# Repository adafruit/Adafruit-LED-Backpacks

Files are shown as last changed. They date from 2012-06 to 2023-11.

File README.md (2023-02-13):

# Adafruit LED Matrix backpacks PCBs

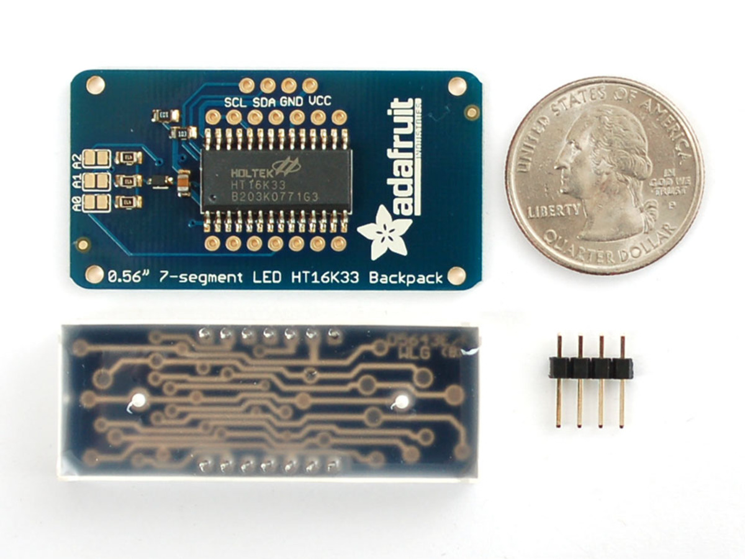
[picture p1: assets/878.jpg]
&nbsp; 
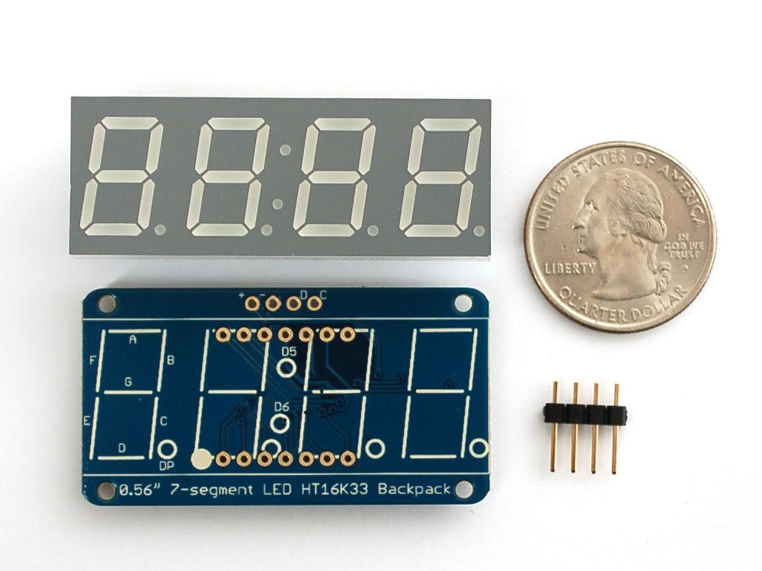
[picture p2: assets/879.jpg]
&nbsp; 
&nbsp; 
<br />
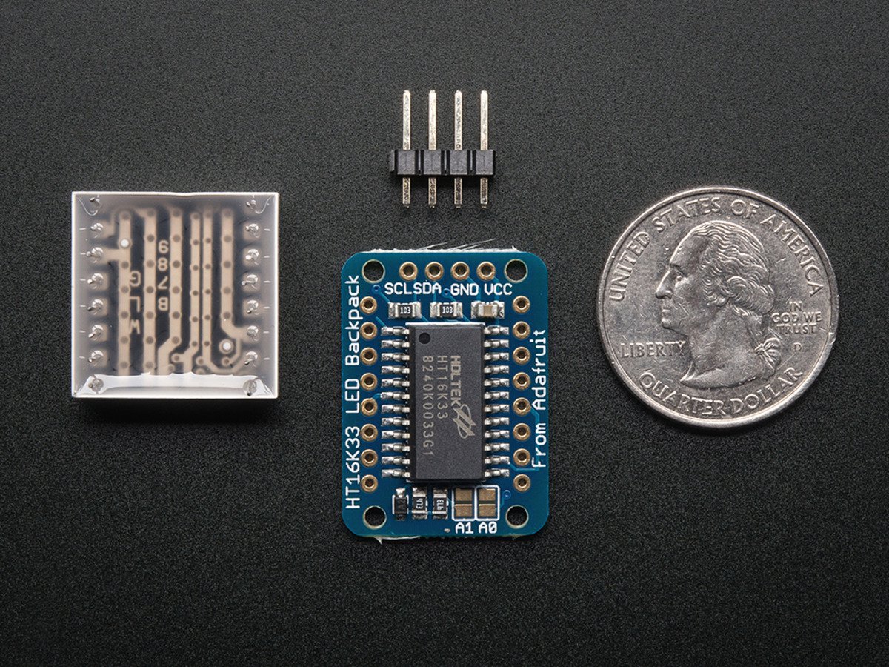
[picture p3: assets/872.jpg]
&nbsp; 
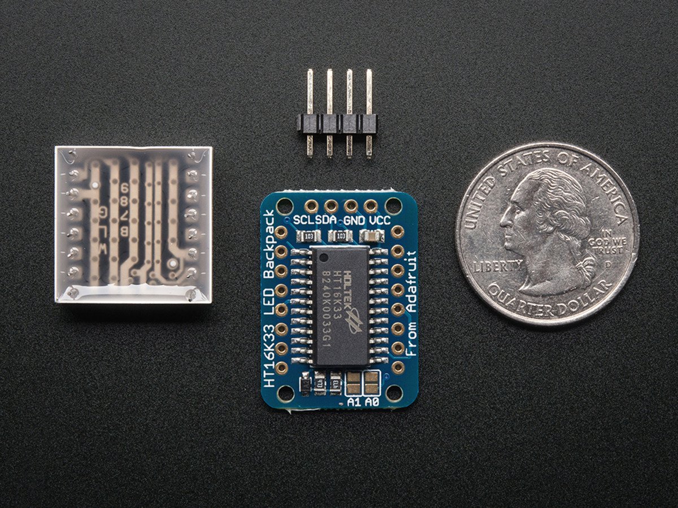
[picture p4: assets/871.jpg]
&nbsp; 
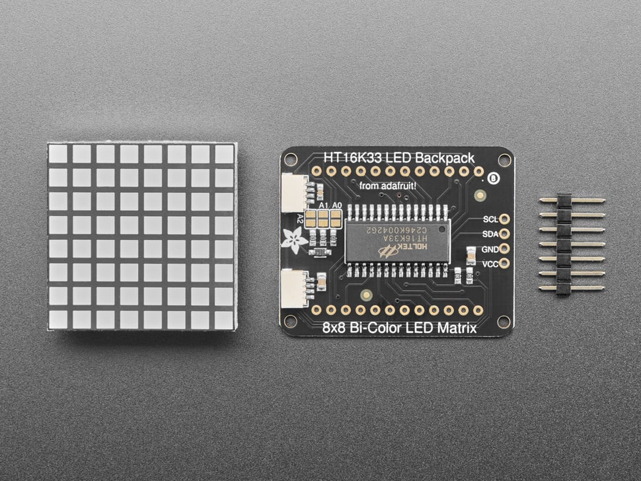
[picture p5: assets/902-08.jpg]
&nbsp; 
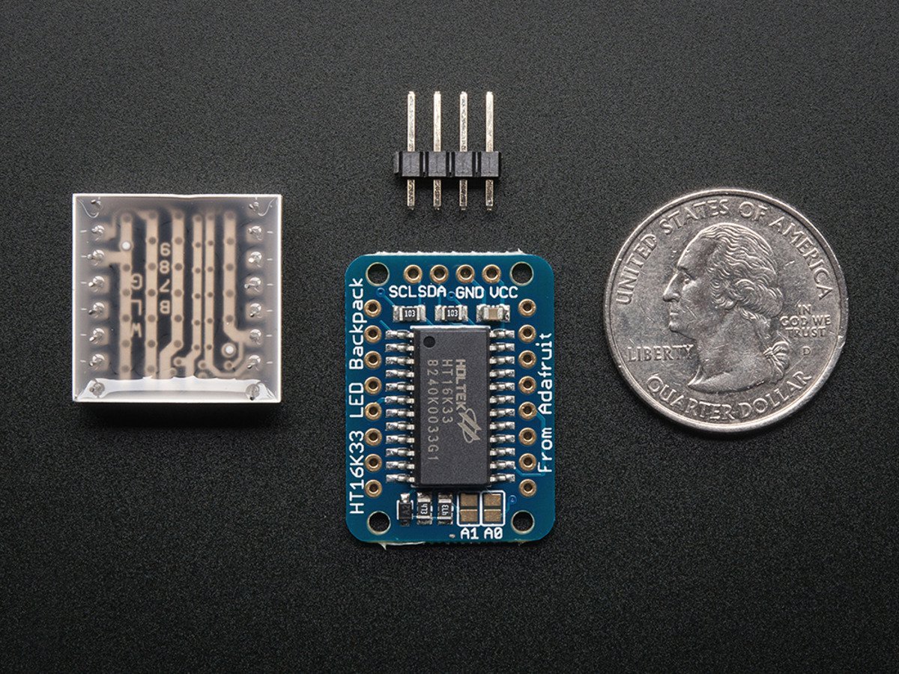
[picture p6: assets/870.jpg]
<br />

What's better than a single LED? Lots of LEDs! A fun way to make a small display is to use an 8x8 matrix or a 4-digit 7-segment display. Matrices like these are 'multiplexed' - so to control all the seven-segment LEDs you need 14 pins. That's a lot of pins, and there are driver chips like the MAX7219 that can control a matrix for you but there's a lot of wiring to set up and they take up a ton of space. Here at Adafruit we feel your pain! After all, wouldn't it be awesome if you could control a matrix without tons of wiring? That's where these adorable LED matrix backpacks come in. We have them in two flavors - a mini 8x8 and a 4-digit 0.56" 7-segment. 

These are the Eagle CAD files for the Adafruit LED Backpack breakouts:
- http://www.adafruit.com/products/878
- http://www.adafruit.com/products/879
- http://www.adafruit.com/products/880
- http://www.adafruit.com/products/881
- http://www.adafruit.com/products/872
- http://www.adafruit.com/products/871
- http://www.adafruit.com/products/870
- https://www.adafruit.com/product/902

These displays use I2C to communicate, 2 pins are required to 
interface. There are multiple selectable I2C addresses. For backpacks 
with 2 Address Select pins: 0x70, 0x71, 0x72 or 0x73. For backpacks 
with 3 Address Select pins: 0x70 thru 0x77

### License

Adafruit invests time and resources providing this open source design, please support Adafruit and open-source hardware by purchasing products from [Adafruit](https://www.adafruit.com)!

All text above must be included in any redistribution

Designed by Limor Fried/Ladyada for Adafruit Industries.
Creative Commons Attribution/Share-Alike, all text above must be included in any redistribution. 
See license.txt for additional information.

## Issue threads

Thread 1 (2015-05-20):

http://www.adafruit.com/products/1427 missing

boelle, 2015-05-20:
i was going to use this one for a project and would like to just drop it in eagle as a part... the pitch between picth i know, but between the rows is to much guess work... any chance this could be added to product info or the board added to git?

Closed 2019-03-19.

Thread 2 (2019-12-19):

Pin numbering on 1.2" 7-segment clock display?

adamwolf, 2019-12-19:
Hi folks!

@matthewbeckler and I were having trouble interpreting the schematic and PCB, because they didn't seem to match around the first two pins of the display.  I opened up the source files in my editor, rather than the exported images, and I noticed that the pins for the display are not in numerical order.

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

I'm curious what the reasoning is for this.  If this was a mistake, is there some way I can help fix it or would that involve internal libraries or something?

Anyway, thanks for all the good work!

Docteh, 2021-07-03:
I ran into this just today looking at the various board layouts.

The PCB file is consistent with the shipped product, so the top pin does connect to Pin 4 of the HT16K33, and the second pin (labeled pin 1 on the PCB) goes to Pin 2 on the HT16K33.

Another interesting quirk is that the PCB layout appears to show the rectangle bleeding off of the board, but on the actual product the silk screen lines are on the board.

ShearonA, 2021-11-21:
This took me way longer to find than it should have.  As the previous two people have identified, the board is correct, but the schematic is incorrect. The schematic shows the decimals/colons being connected to COM0, and they are connected to COM2, with digit 1 (of 4) being connected to COM0, digit 2 (of 4) being connected to COM1, digit 3 being connected to COM3, and digit 4 being connected to COM5.

It doesn't matter if one is using the Arduino libraries, but if you are building your own library in C, this will take a while to figure out that your code won't work if you program to the schematic.

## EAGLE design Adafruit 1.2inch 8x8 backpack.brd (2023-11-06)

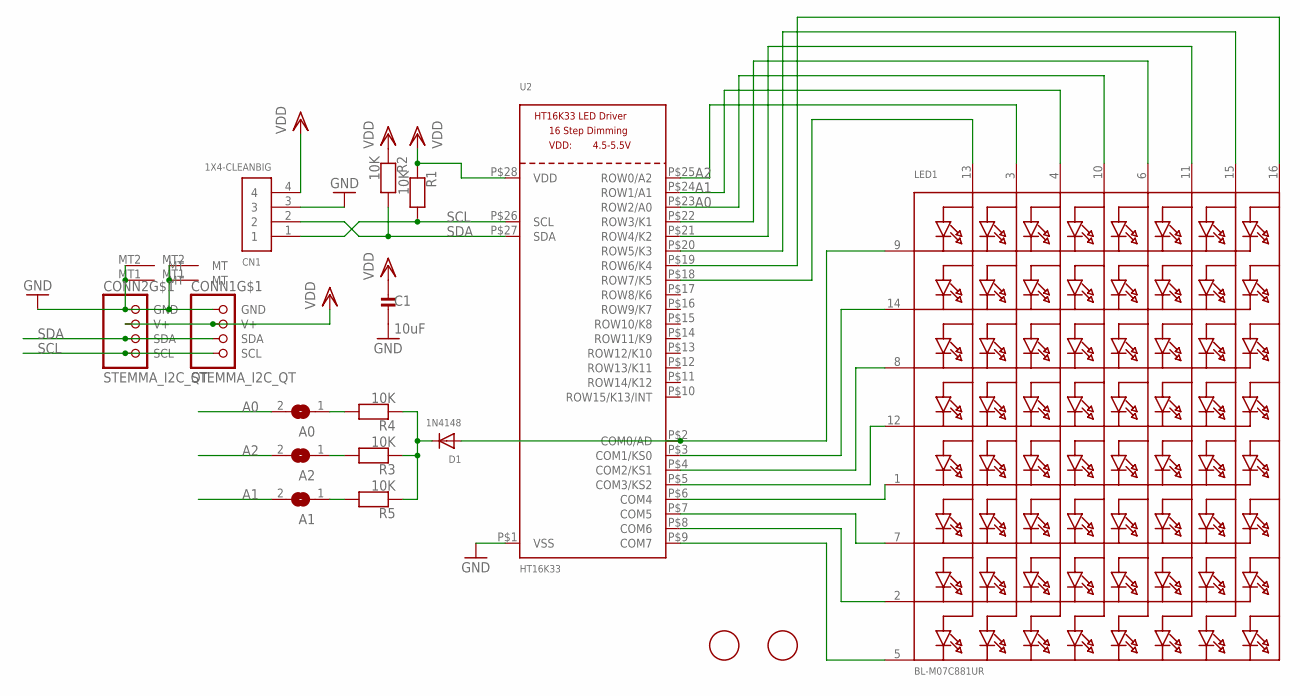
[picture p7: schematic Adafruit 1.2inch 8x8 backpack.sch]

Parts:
A0, A1, A2: SOLDERJUMPERREFLOW_NOPASTE; SOLDERJUMPER_REFLOW_NOPASTE
C1: 10uF; 0805-NO
CN1: 1X4-CLEANBIG; 1X04-CLEANBIG
CONN1, CONN2: STEMMA_I2C_QT; JST_SH4
D1: 1N4148; SOD-323
LED1: BL-M07C881UR; SEGMENT_BL-M12A881UR
R1, R2, R3, R4, R5: 10K; 0603-NO
U2: HT16K33; SOP28_300MIL
U$1, U$2: FIDUCIAL; FIDUCIAL_1MM

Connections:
A0: A0.2, LED1.10 (A4), U2.P$23 (ROW2/A0)
A1: A1.2, LED1.4 (A3), U2.P$24 (ROW1/A1)
A2: A2.2, LED1.3 (A2), U2.P$25 (ROW0/A2)
GND: C1.2, CN1.3, CONN1.1 (GND), CONN1.MT1 (MT), CONN1.MT2 (MT), CONN2.1 (GND), CONN2.MT1 (MT), CONN2.MT2 (MT), U2.P$1 (VSS)
unnamed: LED1.5 (K8), U2.P$9 (COM7)
unnamed: LED1.2 (K7), U2.P$8 (COM6)
unnamed: LED1.7 (K6), U2.P$7 (COM5)
unnamed: LED1.1 (K5), U2.P$6 (COM4)
unnamed: LED1.12 (K4), U2.P$5 (COM3/KS2)
unnamed: LED1.8 (K3), U2.P$4 (COM2/KS1)
unnamed: LED1.14 (K2), U2.P$3 (COM1/KS0)
unnamed: D1.A, LED1.9 (K1), U2.P$2 (COM0/AD)
unnamed: A1.1, R5.2
unnamed: LED1.6 (A5), U2.P$22 (ROW3/K1)
unnamed: LED1.11 (A6), U2.P$21 (ROW4/K2)
unnamed: D1.C, R3.1, R4.1, R5.1
unnamed: LED1.13 (A1), U2.P$18 (ROW7/K5)
unnamed: A2.1, R3.2
unnamed: A0.1, R4.2
SCL: CN1.1, CONN1.4 (SCL), CONN2.4 (SCL), R1.2, U2.P$26 (SCL)
SDA: CN1.2, CONN1.3 (SDA), CONN2.3 (SDA), R2.2, U2.P$27 (SDA)
SEG_F: LED1.15 (A7), U2.P$20 (ROW5/K3)
SEG_G: LED1.16 (A8), U2.P$19 (ROW6/K4)
VDD: C1.1, CN1.4, CONN1.2 (V+), CONN2.2 (V+), R1.1, R2.1, U2.P$28 (VDD)

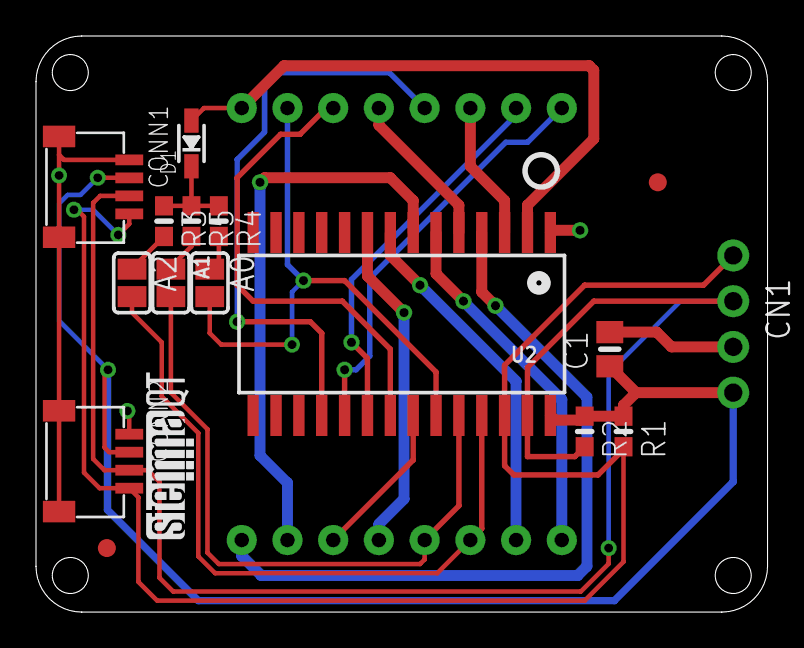
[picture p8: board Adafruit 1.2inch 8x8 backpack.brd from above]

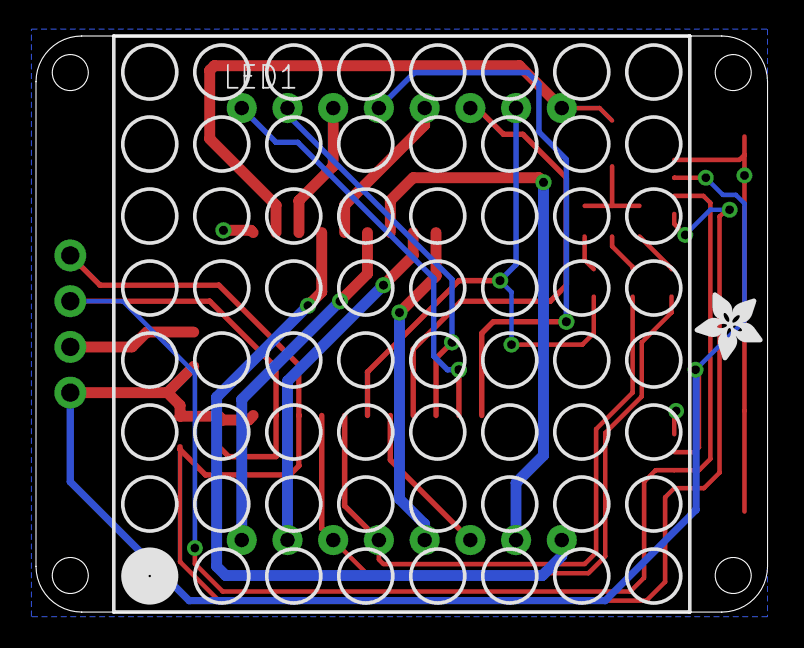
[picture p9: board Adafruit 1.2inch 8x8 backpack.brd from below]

Board: 2 copper layers, 40.6 x 32.0 mm, 34 parts (6 on the bottom side), 24 nets.

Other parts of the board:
PLABEL0: PLABEL0
PLABEL1: PLABEL1
PLABEL2: PLABEL2
PLABEL3: PLABEL3
PLABEL4: PLABEL4
PLABEL5: PLABEL5
PLABEL6: PLABEL6
PLABEL7: PLABEL7
PLABEL8: PLABEL8
PLABEL9: PLABEL9
PLABEL10: PLABEL10
PLABEL11: PLABEL11
PLABEL12: PLABEL12
PLABEL13: PLABEL13
U$3: ADAFRUIT_3.5MM
U$4: PCBFEAT-REV-040
U$5: STEMMAQT

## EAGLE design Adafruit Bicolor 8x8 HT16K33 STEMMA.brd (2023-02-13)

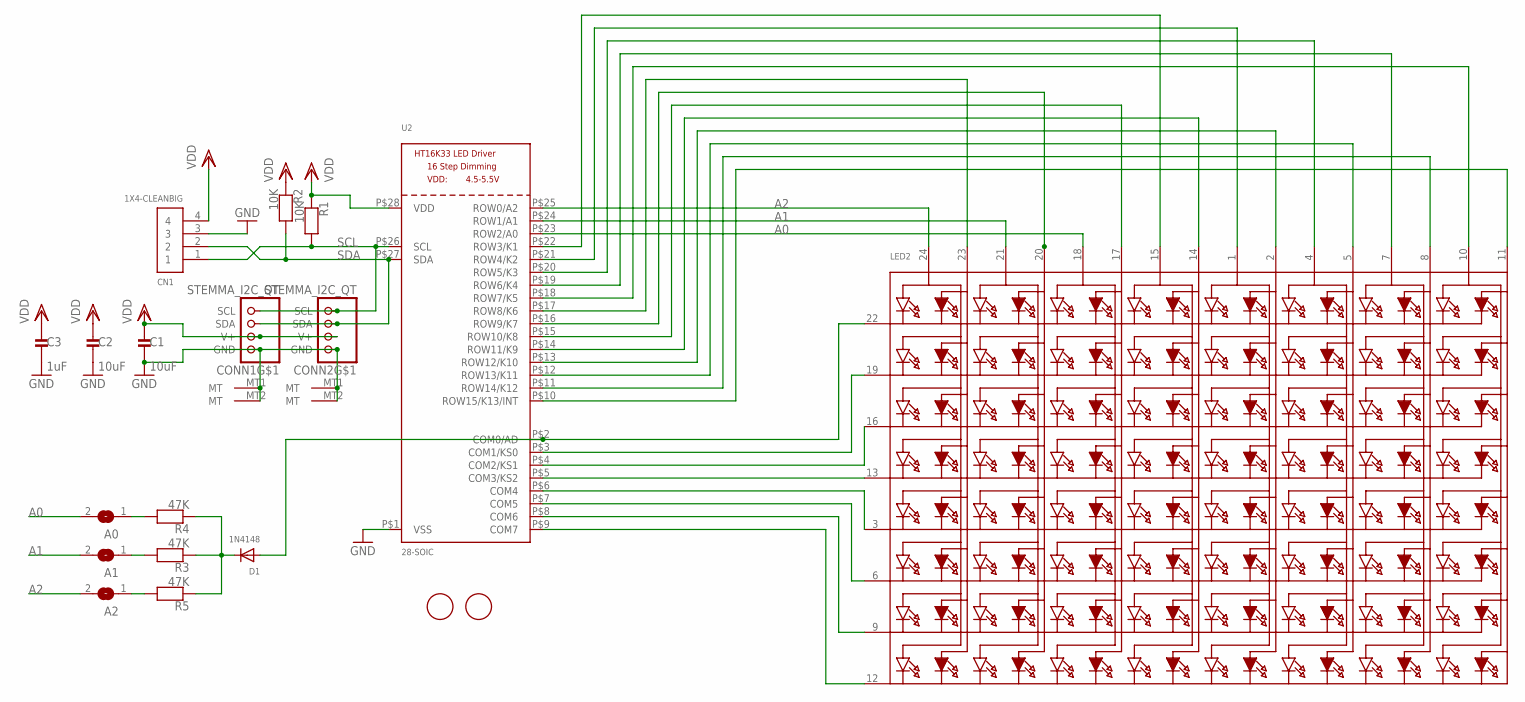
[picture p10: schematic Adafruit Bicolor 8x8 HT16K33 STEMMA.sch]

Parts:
A0, A1, A2: SOLDERJUMPERREFLOW_NOPASTE; SOLDERJUMPER_REFLOW_NOPASTE
C1, C2: 10uF; 0805-NO
C3: 1uF; 0603-NO
CN1: 1X4-CLEANBIG; 1X04-CLEANBIG
CONN1, CONN2: STEMMA_I2C_QT; JST_SH4
D1: 1N4148; SOD-323
LED2: DISP_SEGMENT_8X8_BICOLOR_ROWCATHODEMI2A883XX; SEGMENT_BICOL_BL-M12A883XX
R1, R2: 10K; 0603-NO
R3, R4, R5: 47K; 0603-NO
U2: 28-SOIC; SOP28_300MIL
U$1, U$2: FIDUCIAL; FIDUCIAL_1MM

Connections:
A0: A0.2, LED2.18 (A5), U2.P$23 (ROW2/A0)
A1: A1.2, LED2.21 (A3), U2.P$24 (ROW1/A1)
A2: A2.2, LED2.24 (A1), U2.P$25 (ROW0/A2)
GND: C1.2, C2.2, C3.2, CN1.3, CONN1.1 (GND), CONN1.MT1 (MT), CONN1.MT2 (MT), CONN2.1 (GND), CONN2.MT1 (MT), CONN2.MT2 (MT), U2.P$1 (VSS)
unnamed: LED2.12 (K8), U2.P$9 (COM7)
unnamed: LED2.9 (K7), U2.P$8 (COM6)
unnamed: LED2.6 (K6), U2.P$7 (COM5)
unnamed: LED2.3 (K5), U2.P$6 (COM4)
unnamed: LED2.13 (K4), U2.P$5 (COM3/KS2)
unnamed: LED2.16 (K3), U2.P$4 (COM2/KS1)
unnamed: LED2.19 (K2), U2.P$3 (COM1/KS0)
unnamed: D1.A, LED2.22 (K1), U2.P$2 (COM0/AD)
unnamed: A2.1, R5.2
unnamed: LED2.8 (A14), U2.P$11 (ROW14/K12)
unnamed: LED2.5 (A12), U2.P$12 (ROW13/K11)
unnamed: LED2.11 (A16), U2.P$10 (ROW15/K13/INT)
unnamed: D1.C, R3.1, R4.1, R5.1
unnamed: A1.1, R3.2
unnamed: A0.1, R4.2
unnamed: LED2.10 (A15), U2.P$18 (ROW7/K5)
unnamed: LED2.7 (A13), U2.P$19 (ROW6/K4)
unnamed: LED2.1 (A9), U2.P$21 (ROW4/K2)
unnamed: LED2.15 (A7), U2.P$22 (ROW3/K1)
unnamed: LED2.4 (A11), U2.P$20 (ROW5/K3)
unnamed: LED2.23 (A2), U2.P$17 (ROW8/K6)
unnamed: LED2.20 (A4), U2.P$16 (ROW9/K7)
unnamed: LED2.14 (A8), U2.P$14 (ROW11/K9)
unnamed: LED2.17 (A6), U2.P$15 (ROW10/K8)
unnamed: LED2.2 (A10), U2.P$13 (ROW12/K10)
SCL: CN1.1, CONN1.4 (SCL), CONN2.4 (SCL), R1.2, U2.P$26 (SCL)
SDA: CN1.2, CONN1.3 (SDA), CONN2.3 (SDA), R2.2, U2.P$27 (SDA)
VDD: C1.1, C2.1, C3.1, CN1.4, CONN1.2 (V+), CONN2.2 (V+), R1.1, R2.1, U2.P$28 (VDD)

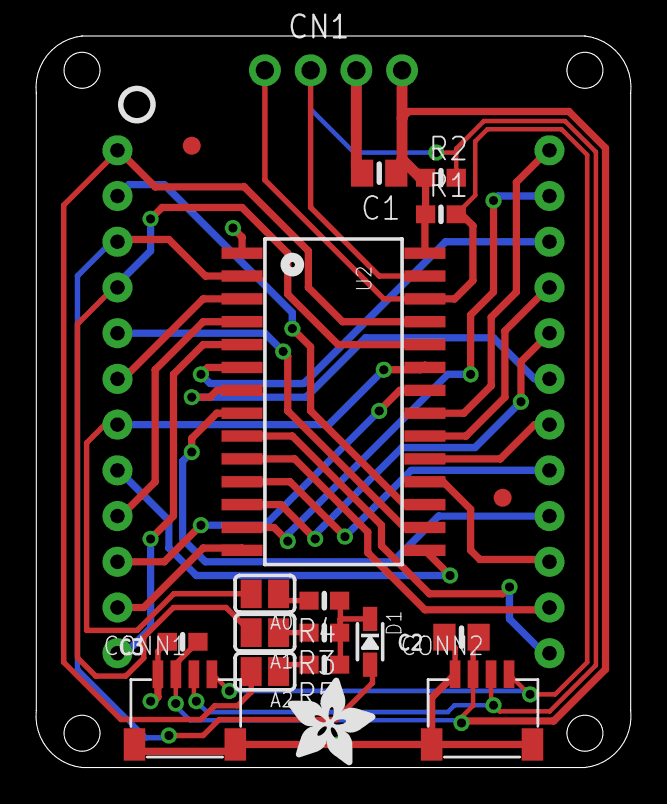
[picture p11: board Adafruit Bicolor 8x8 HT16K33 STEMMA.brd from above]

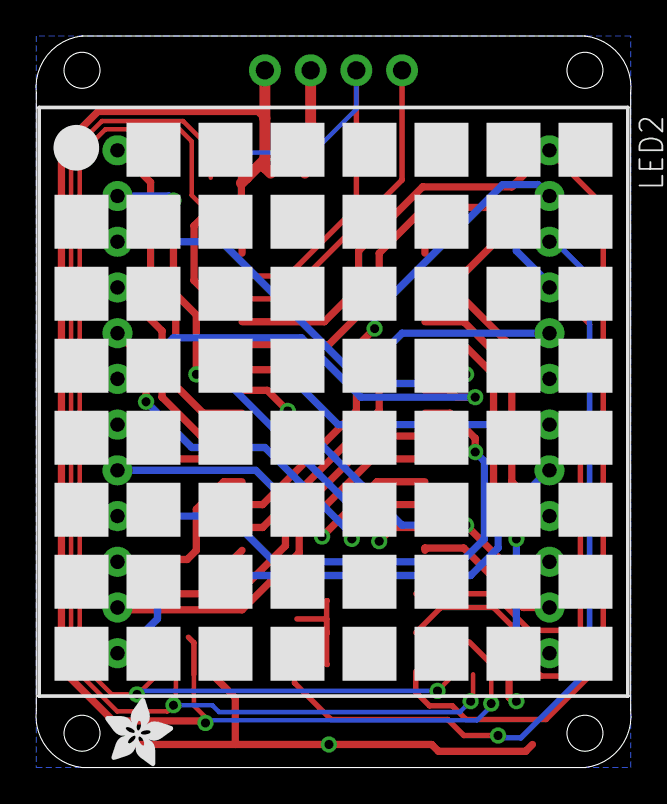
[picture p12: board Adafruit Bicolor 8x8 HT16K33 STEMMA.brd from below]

Board: 2 copper layers, 33.1 x 40.6 mm, 37 parts (7 on the bottom side), 32 nets.

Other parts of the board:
E$2: ADAFRUIT_3.5MM
PLABEL0: PLABEL0
PLABEL1: PLABEL1
PLABEL2: PLABEL2
PLABEL3: PLABEL3
PLABEL4: PLABEL4
PLABEL5: PLABEL5
PLABEL6: PLABEL6
PLABEL7: PLABEL7
PLABEL8: PLABEL8
PLABEL9: PLABEL9
PLABEL10: PLABEL10
PLABEL11: PLABEL11
PLABEL12: PLABEL12
PLABEL13: PLABEL13
PLABEL14: PLABEL14
U$3: ADAFRUIT_5MM
U$4: PCBFEAT-REV-040

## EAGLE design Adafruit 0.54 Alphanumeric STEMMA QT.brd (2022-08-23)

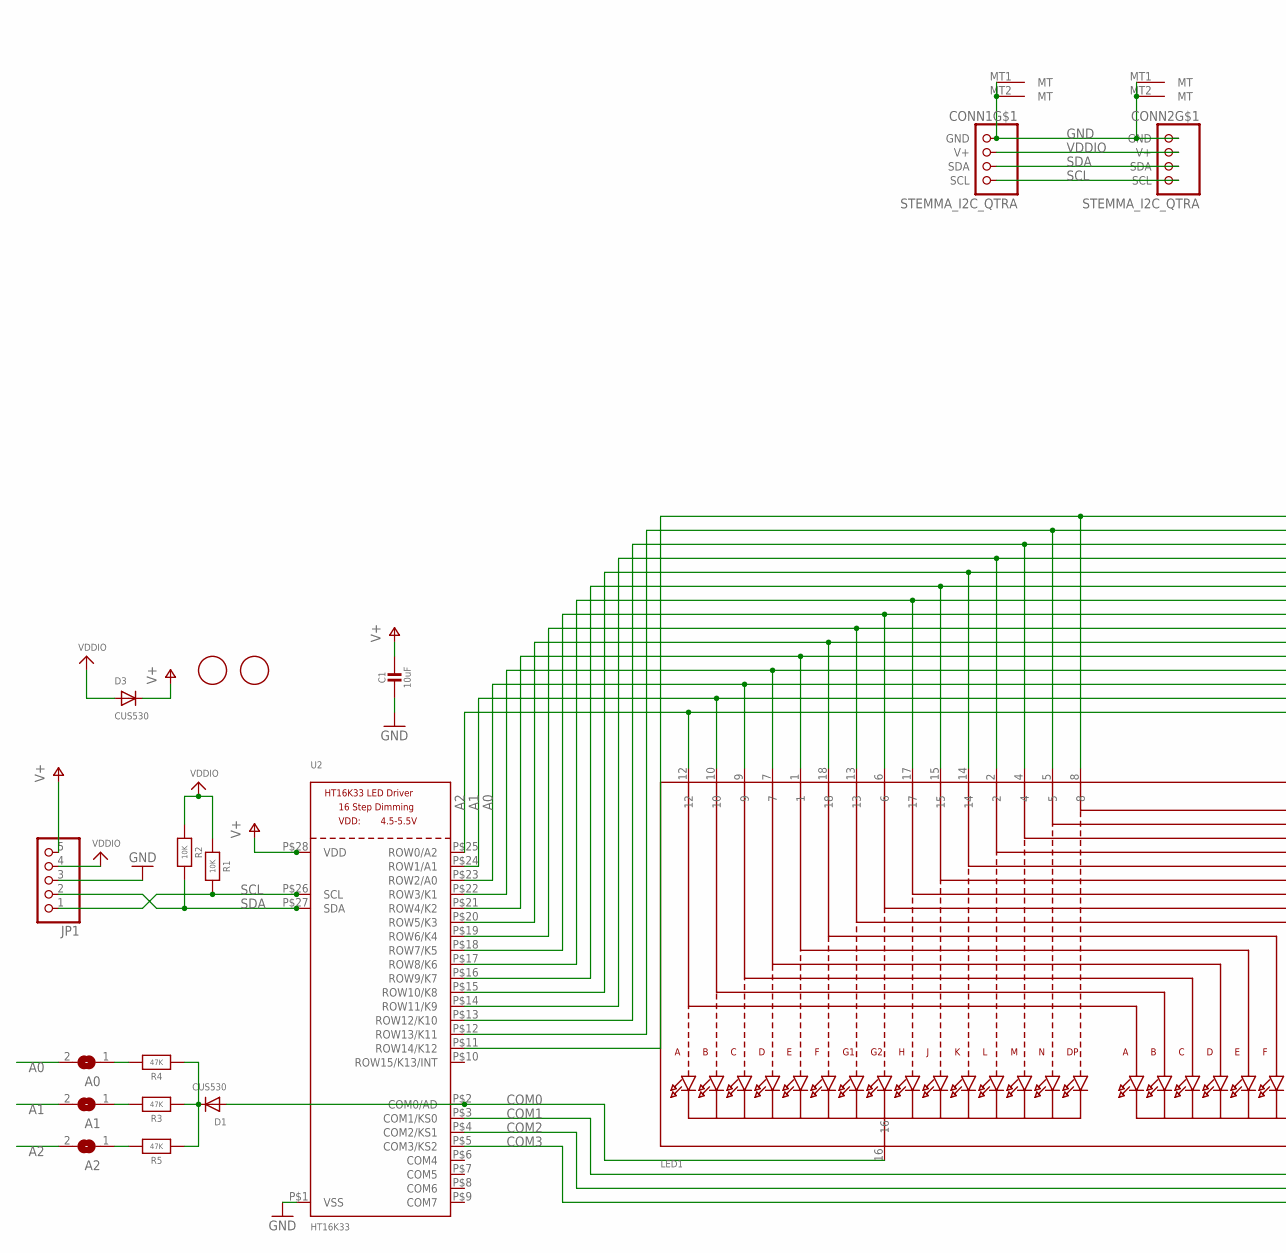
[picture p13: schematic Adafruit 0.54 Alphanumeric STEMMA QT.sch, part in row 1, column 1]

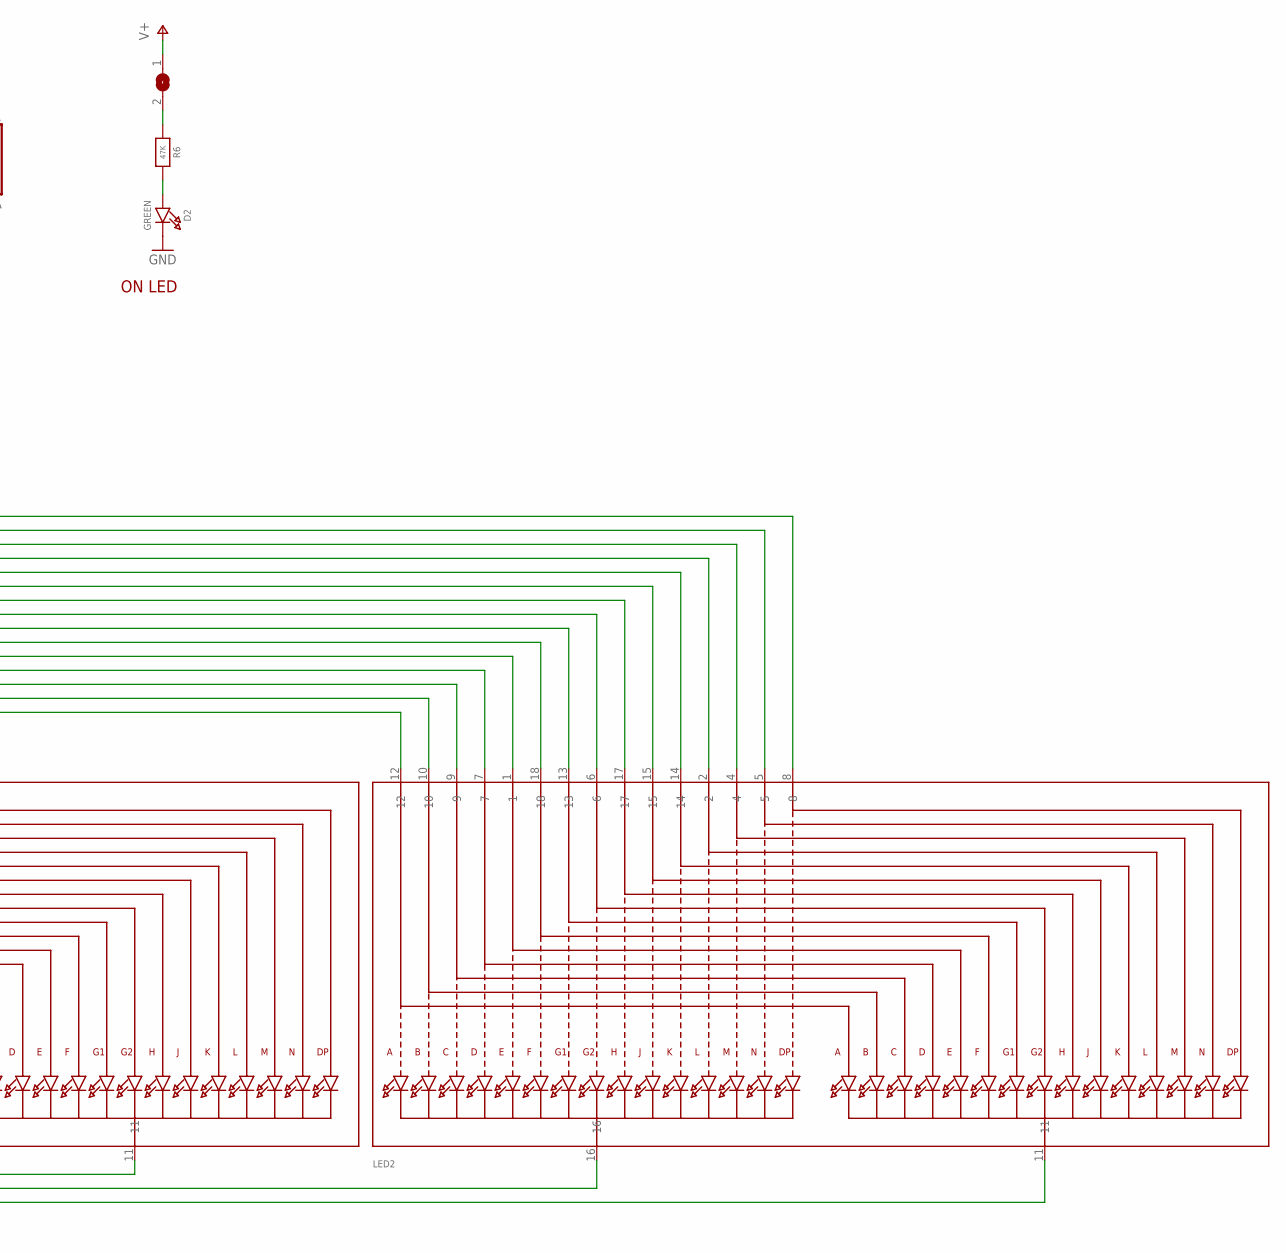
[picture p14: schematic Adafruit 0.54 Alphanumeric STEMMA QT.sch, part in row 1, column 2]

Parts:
A0, A1, A2: SOLDERJUMPERREFLOW_NOPASTE; SOLDERJUMPER_REFLOW_NOPASTE
C1: 10uF; 0805-NO
CONN1, CONN2: STEMMA_I2C_QTRA; JST_SH4_RA
D1, D3: CUS530; SOD-323F
D2: GREEN; CHIPLED_0603_NOOUTLINE
JP1: HEADER-1X570MIL; 1X05_ROUND_70
LED1, LED2: DISP_SEGMENT_STARBURST_DUAL_COMMONCATHODE; SEGMENT_STARTBUST_DUAL_KWA-541CBB
LEDJMP: SOLDERJUMPERCLOSED; SOLDERJUMPER_CLOSEDWIRE
R1, R2: 10K; 0603-NO
R3, R4, R5, R6: 47K; 0603-NO
U2: HT16K33; SOP28_300MIL_SKINNY
U$1, U$2: FIDUCIAL; FIDUCIAL_1MM

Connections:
A0: A0.2, LED1.9, LED2.9, U2.P$23 (ROW2/A0)
A1: A1.2, LED1.10, LED2.10, U2.P$24 (ROW1/A1)
A2: A2.2, LED1.12, LED2.12, U2.P$25 (ROW0/A2)
COM0: D1.A, LED1.16, U2.P$2 (COM0/AD)
COM1: LED1.11, U2.P$3 (COM1/KS0)
COM2: LED2.16, U2.P$4 (COM2/KS1)
COM3: LED2.11, U2.P$5 (COM3/KS2)
GND: C1.2, CONN1.1 (GND), CONN1.MT1 (MT), CONN1.MT2 (MT), CONN2.1 (GND), CONN2.MT1 (MT), CONN2.MT2 (MT), D2.C, JP1.3, U2.P$1 (VSS)
unnamed: D1.C, R3.1, R4.1, R5.1
unnamed: D2.A, R6.2
unnamed: LED1.17, LED2.17, U2.P$17 (ROW8/K6)
unnamed: LED1.15, LED2.15, U2.P$16 (ROW9/K7)
unnamed: LED1.14, LED2.14, U2.P$15 (ROW10/K8)
unnamed: A2.1, R5.2
unnamed: LED1.2, LED2.2, U2.P$14 (ROW11/K9)
unnamed: LED1.4, LED2.4, U2.P$13 (ROW12/K10)
unnamed: LED1.7, LED2.7, U2.P$22 (ROW3/K1)
unnamed: LED1.1, LED2.1, U2.P$21 (ROW4/K2)
unnamed: LED1.18, LED2.18, U2.P$20 (ROW5/K3)
unnamed: LED1.13, LED2.13, U2.P$19 (ROW6/K4)
unnamed: LED1.5, LED2.5, U2.P$12 (ROW13/K11)
unnamed: LED1.8, LED2.8, U2.P$11 (ROW14/K12)
unnamed: LED1.6, LED2.6, U2.P$18 (ROW7/K5)
unnamed: LEDJMP.2, R6.1
unnamed: A1.1, R3.2
unnamed: A0.1, R4.2
SCL: CONN1.4 (SCL), CONN2.4 (SCL), JP1.1, R1.2, U2.P$26 (SCL)
SDA: CONN1.3 (SDA), CONN2.3 (SDA), JP1.2, R2.2, U2.P$27 (SDA)
V+: C1.1, D3.C, JP1.5, LEDJMP.1, U2.P$28 (VDD)
VDDIO: CONN1.2 (V+), CONN2.2 (V+), D3.A, JP1.4, R1.1, R2.1

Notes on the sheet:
ON LED

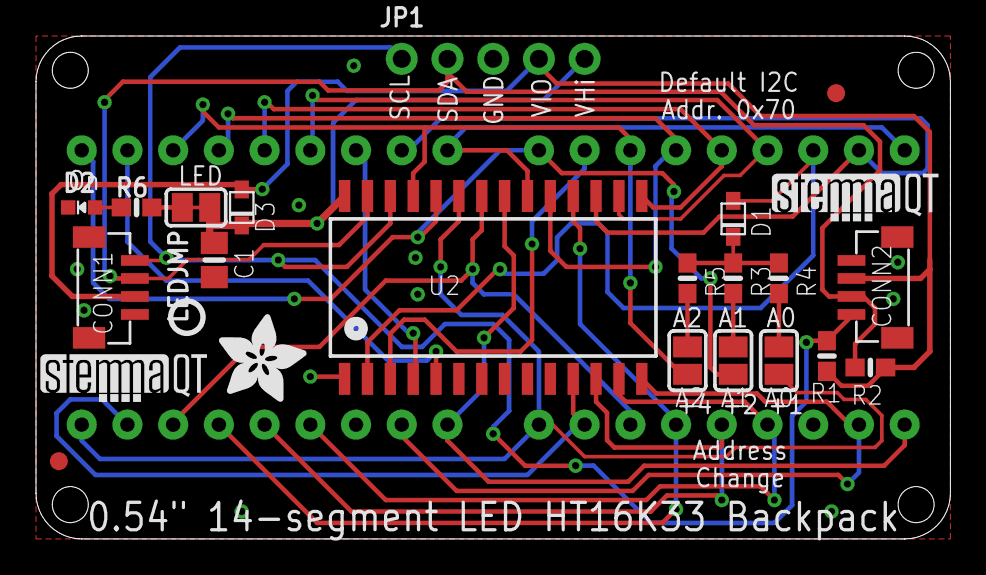
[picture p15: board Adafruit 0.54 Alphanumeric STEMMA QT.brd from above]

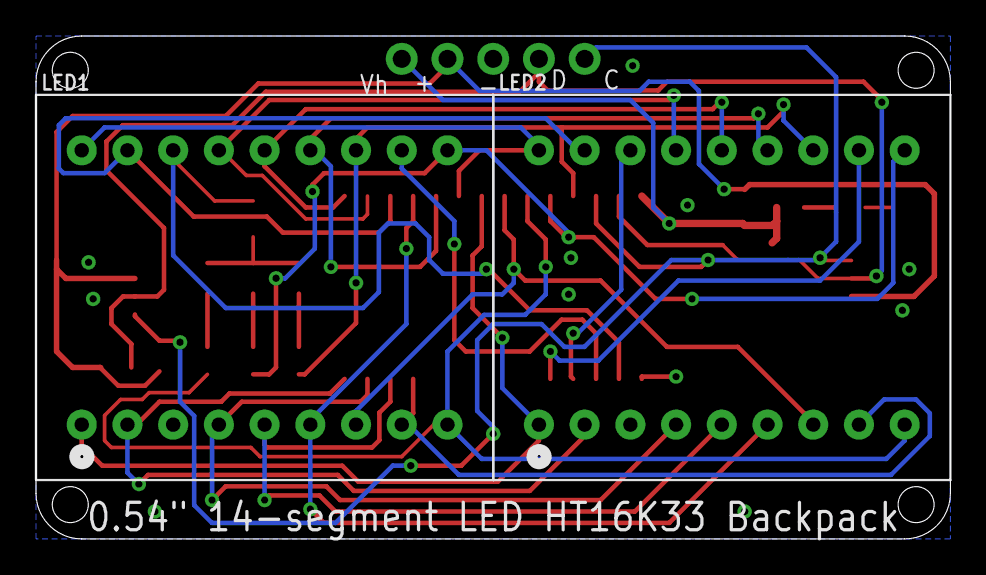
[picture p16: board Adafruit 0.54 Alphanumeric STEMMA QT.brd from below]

Board: 2 copper layers, 50.8 x 27.9 mm, 26 parts (2 on the bottom side), 30 nets.

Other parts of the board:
U$3: ADAFRUIT_5MM
U$6, U$7: STEMMAQT
U$8: PCBFEAT-REV-040

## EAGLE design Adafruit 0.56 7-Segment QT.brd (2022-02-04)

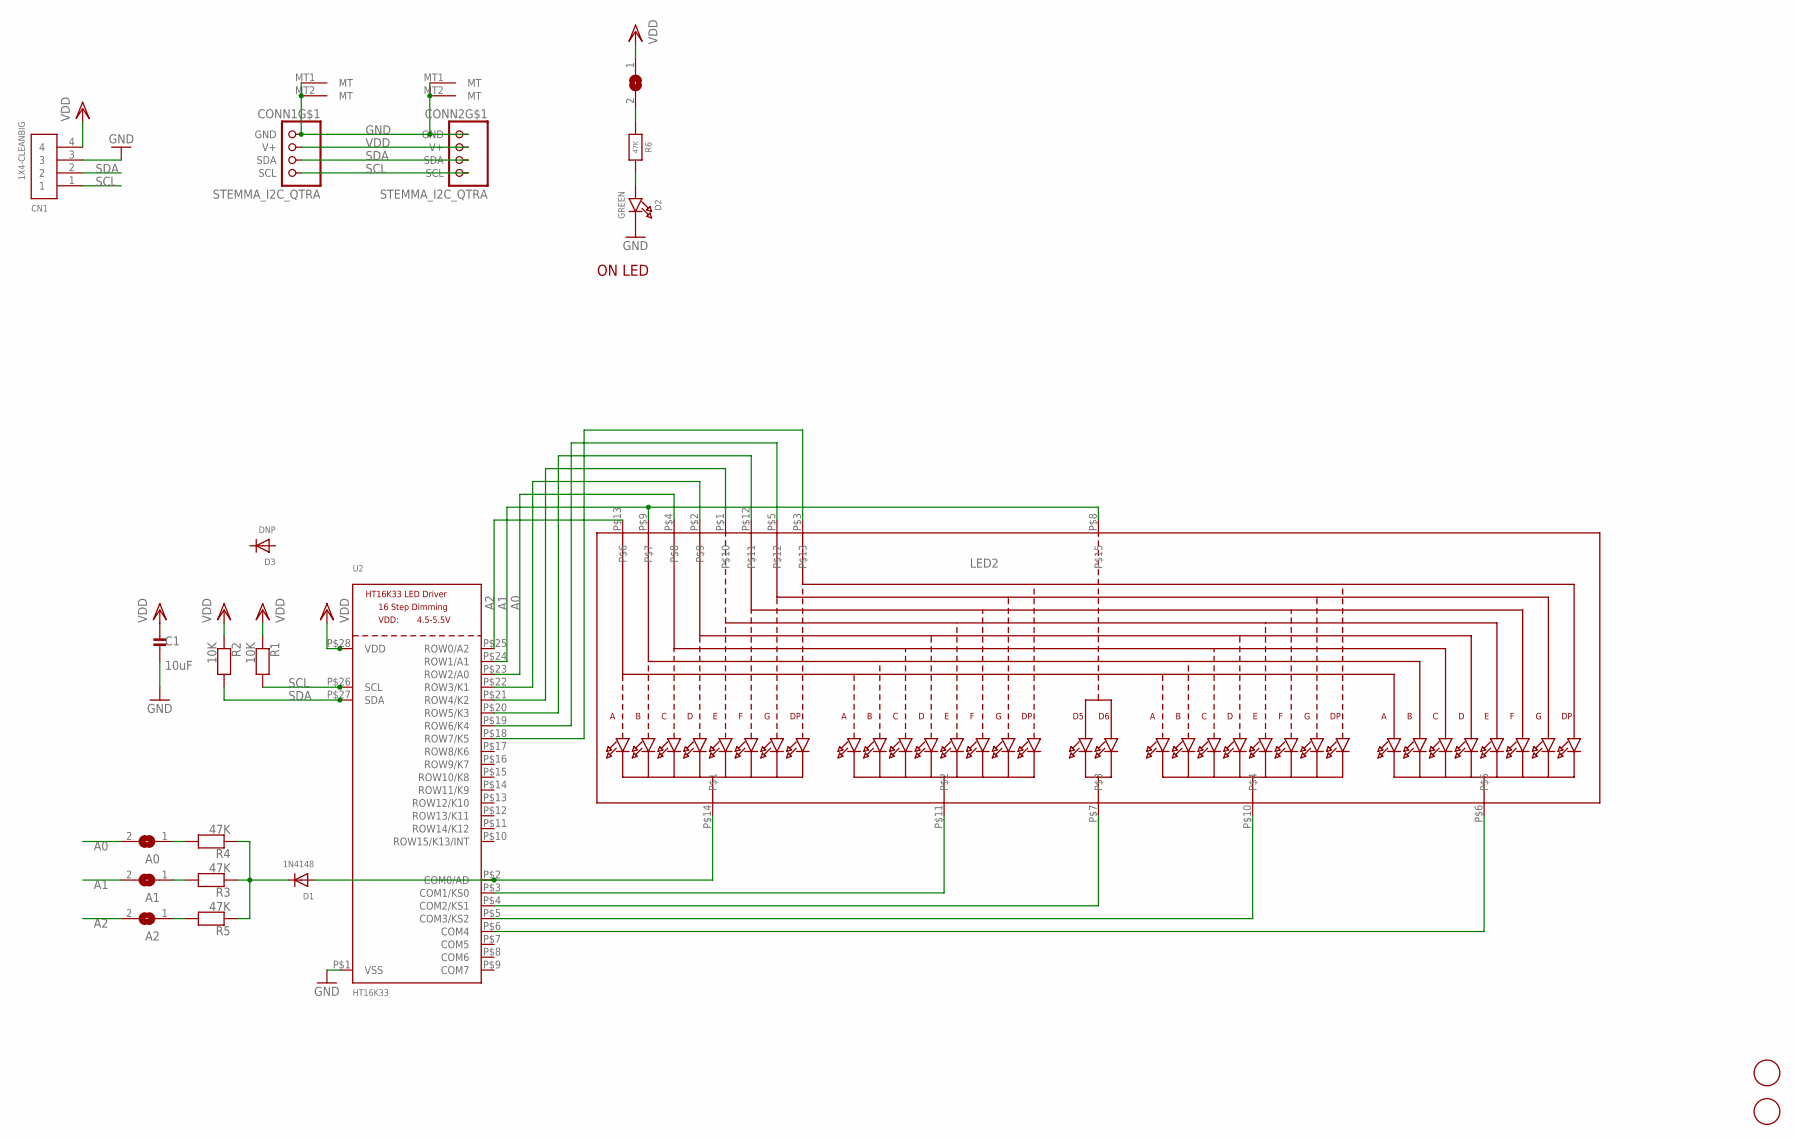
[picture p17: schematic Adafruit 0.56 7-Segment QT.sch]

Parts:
A0, A1, A2: SOLDERJUMPER; SOLDERJUMPER_ARROW_NOPASTE
C1: 10uF; 0805_10MGAP
CN1: 1X4-CLEANBIG; 1X04-CLEANBIG
CONN1, CONN2: STEMMA_I2C_QTRA; JST_SH4_RA
D1: 1N4148; SOD-323F
D2: GREEN; CHIPLED_0603_NOOUTLINE
D3: DNP; SOD-323F
LED2: DISP_SEGMENT_4DIGIT_BL-Q56C43; SEGMENT-BL-Q56C43
LEDJMP: SOLDERJUMPERCLOSED; SOLDERJUMPER_CLOSEDWIRE
R1, R2: 10K; 0603-NO
R3, R4, R5, R6: 47K; 0603-NO
U2: HT16K33; SOP28_300MIL_SKINNY
U$1, U$2: FIDUCIAL; FIDUCIAL_1MM

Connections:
A0: A0.2, LED2.P$4, U2.P$23 (ROW2/A0)
A1: A1.2, LED2.P$8, LED2.P$9, U2.P$24 (ROW1/A1)
A2: A2.2, LED2.P$13, U2.P$25 (ROW0/A2)
GND: C1.2, CN1.3, CONN1.1 (GND), CONN1.MT1 (MT), CONN1.MT2 (MT), CONN2.1 (GND), CONN2.MT1 (MT), CONN2.MT2 (MT), D2.C, U2.P$1 (VSS)
unnamed: D1.C, R3.1, R4.1, R5.1
unnamed: D1.A, LED2.P$14, U2.P$2 (COM0/AD)
unnamed: LED2.P$11, U2.P$3 (COM1/KS0)
unnamed: LED2.P$7, U2.P$4 (COM2/KS1)
unnamed: LED2.P$10, U2.P$5 (COM3/KS2)
unnamed: LED2.P$6, U2.P$6 (COM4)
unnamed: A2.1, R5.2
unnamed: D2.A, R6.2
unnamed: LEDJMP.2, R6.1
unnamed: LED2.P$2, U2.P$22 (ROW3/K1)
unnamed: LED2.P$1, U2.P$21 (ROW4/K2)
unnamed: LED2.P$12, U2.P$20 (ROW5/K3)
unnamed: LED2.P$5, U2.P$19 (ROW6/K4)
unnamed: LED2.P$3, U2.P$18 (ROW7/K5)
unnamed: A1.1, R3.2
unnamed: A0.1, R4.2
SCL: CN1.1, CONN1.4 (SCL), CONN2.4 (SCL), R1.2, U2.P$26 (SCL)
SDA: CN1.2, CONN1.3 (SDA), CONN2.3 (SDA), R2.2, U2.P$27 (SDA)
VDD: C1.1, CN1.4, CONN1.2 (V+), CONN2.2 (V+), LEDJMP.1, R1.1, R2.1, U2.P$28 (VDD)

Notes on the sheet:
ON LED

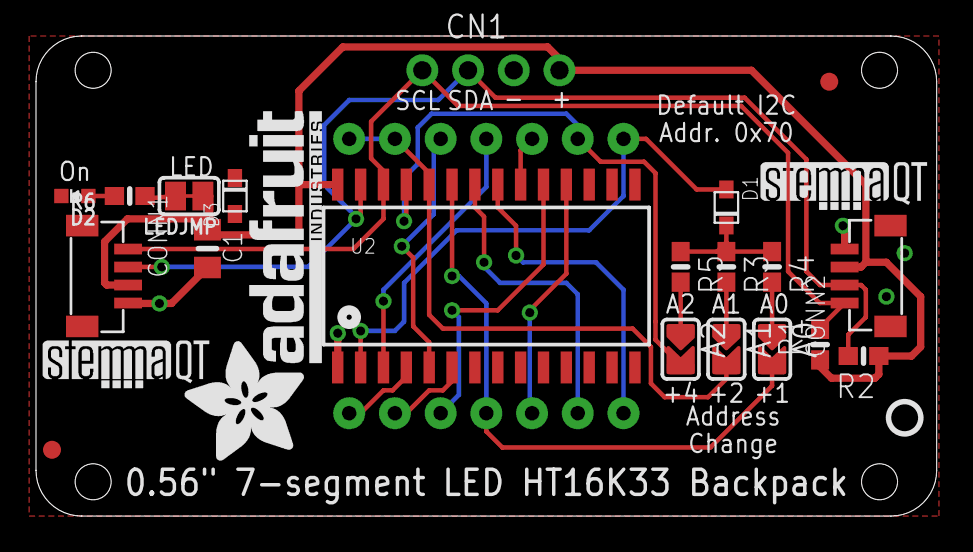
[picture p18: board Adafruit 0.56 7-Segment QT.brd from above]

Board: 2 copper layers, 50.0 x 26.7 mm, 25 parts (1 on the bottom side), 23 nets.

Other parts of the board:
U$3: ADAFRUIT_TEXT_20MM
U$5, U$6: STEMMAQT
U$7: PCBFEAT-REV-040

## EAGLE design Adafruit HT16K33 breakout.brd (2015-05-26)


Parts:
A0, A1, A2: SOLDERJUMPERREFLOW_NOPASTE; SOLDERJUMPER_REFLOW_NOPASTE
C1: 10uF; C0805
D1: 1N4148; SOD-323F
JP1, JP2: PINHD-1X14-CB; 1X14-CB
R1, R2: 10K; R0805
R3, R4, R5: 47K; R0805
U2: 28-SOIC; SOP28_300MIL
U$1, U$2, U$6: FIDUCIAL; FIDUCIAL_1MM
U$4, U$5: MOUNTINGHOLE2.5; MOUNTINGHOLE_2.5_PLATED

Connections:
A0: A0.2, JP1.9, U2.P$23 (ROW2/A0)
A1: A1.2, JP1.10, U2.P$24 (ROW1/A1)
A2: A2.2, JP1.11, U2.P$25 (ROW0/A2)
ANOD3: JP1.8, U2.P$22 (ROW3/K1)
ANOD4: JP1.7, U2.P$21 (ROW4/K2)
ANOD5: JP1.6, U2.P$20 (ROW5/K3)
ANOD6: JP1.5, U2.P$19 (ROW6/K4)
ANOD7: JP1.4, U2.P$18 (ROW7/K5)
ANOD8: JP1.3, U2.P$17 (ROW8/K6)
ANOD9: JP1.2, U2.P$16 (ROW9/K7)
ANOD10: JP1.1, U2.P$15 (ROW10/K8)
ANOD11: JP2.14, U2.P$14 (ROW11/K9)
ANOD12: JP2.13, U2.P$13 (ROW12/K10)
ANOD13: JP2.12, U2.P$12 (ROW13/K11)
ANOD14: JP2.11, U2.P$11 (ROW14/K12)
ANOD15: JP2.10, U2.P$10 (ROW15/K13/INT)
CATH0: D1.A, JP2.2, U2.P$2 (COM0/AD)
CATH1: JP2.3, U2.P$3 (COM1/KS0)
CATH2: JP2.4, U2.P$4 (COM2/KS1)
CATH3: JP2.5, U2.P$5 (COM3/KS2)
CATH4: JP2.6, U2.P$6 (COM4)
CATH5: JP2.7, U2.P$7 (COM5)
CATH6: JP2.8, U2.P$8 (COM6)
CATH7: JP2.9, U2.P$9 (COM7)
GND: C1.2, JP2.1, U2.P$1 (VSS)
unnamed: A2.1, R5.2
unnamed: D1.C, R3.1, R4.1, R5.1
unnamed: A1.1, R3.2
unnamed: A0.1, R4.2
SCL: JP1.12, R1.2, U2.P$26 (SCL)
SDA: JP1.13, R2.2, U2.P$27 (SDA)
VDD: C1.1, JP1.14, R1.1, R2.1, U2.P$28 (VDD)


Board: 2 copper layers, 20.3 x 35.6 mm, 20 parts (1 on the bottom side), 32 nets.

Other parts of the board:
U$3: ADAFRUIT_3.5MM
U$7: ADAFRUIT_5MM

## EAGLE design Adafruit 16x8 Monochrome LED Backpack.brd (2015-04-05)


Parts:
A0, A1, A2: SOLDERJUMPERREFLOW_NOPASTE; SOLDERJUMPER_REFLOW_NOPASTE
C1, C2, C3: 10uF; 0805-NO
CN1: 1X4-CLEANBIG; 1X04-CLEANBIG
D1: 1N4148; SOD-323F
LED1, LED2: DISP_SEGMENT_8X8_ROWCATHODEM12A881UR; SEGMENT_BL-M12A881UR
R1: 10K; R0805
R2, R3, R4, R5: 10K; 0805-NO
U2: 28-SOIC; SOP28_300MIL
U$1, U$2: FIDUCIAL; FIDUCIAL_1MM

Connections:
A0: A0.2, LED1.4 (A3), U2.P$23 (ROW2/A0)
A1: A1.2, LED1.3 (A2), U2.P$24 (ROW1/A1)
A2: A2.2, LED1.13 (A1), U2.P$25 (ROW0/A2)
GND: C1.2, C2.2, C3.2, CN1.3, U2.P$1 (VSS)
unnamed: LED1.5 (K8), LED2.5 (K8), U2.P$9 (COM7)
unnamed: LED1.2 (K7), LED2.2 (K7), U2.P$8 (COM6)
unnamed: LED1.7 (K6), LED2.7 (K6), U2.P$7 (COM5)
unnamed: LED1.1 (K5), LED2.1 (K5), U2.P$6 (COM4)
unnamed: LED1.12 (K4), LED2.12 (K4), U2.P$5 (COM3/KS2)
unnamed: LED1.8 (K3), LED2.8 (K3), U2.P$4 (COM2/KS1)
unnamed: LED1.14 (K2), LED2.14 (K2), U2.P$3 (COM1/KS0)
unnamed: D1.A, LED1.9 (K1), LED2.9 (K1), U2.P$2 (COM0/AD)
unnamed: A2.1, R5.2
unnamed: LED2.15 (A7), U2.P$11 (ROW14/K12)
unnamed: LED2.11 (A6), U2.P$12 (ROW13/K11)
unnamed: LED2.16 (A8), U2.P$10 (ROW15/K13/INT)
unnamed: D1.C, R3.1, R4.1, R5.1
unnamed: A1.1, R3.2
unnamed: A0.1, R4.2
unnamed: LED1.16 (A8), U2.P$18 (ROW7/K5)
unnamed: LED1.15 (A7), U2.P$19 (ROW6/K4)
unnamed: LED1.6 (A5), U2.P$21 (ROW4/K2)
unnamed: LED1.10 (A4), U2.P$22 (ROW3/K1)
unnamed: LED1.11 (A6), U2.P$20 (ROW5/K3)
unnamed: LED2.13 (A1), U2.P$17 (ROW8/K6)
unnamed: LED2.3 (A2), U2.P$16 (ROW9/K7)
unnamed: LED2.10 (A4), U2.P$14 (ROW11/K9)
unnamed: LED2.4 (A3), U2.P$15 (ROW10/K8)
unnamed: LED2.6 (A5), U2.P$13 (ROW12/K10)
SCL: CN1.1, R1.2, U2.P$26 (SCL)
SDA: CN1.2, R2.2, U2.P$27 (SDA)
VDD: C1.1, C2.1, C3.1, CN1.4, R1.1, R2.1, U2.P$28 (VDD)

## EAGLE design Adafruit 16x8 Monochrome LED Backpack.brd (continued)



Board: 2 copper layers, 72.4 x 32.0 mm, 20 parts (3 on the bottom side), 32 nets.

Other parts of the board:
U$3: ADAFRUIT_TEXT_20MM
U$4: ADAFRUIT_3.5MM

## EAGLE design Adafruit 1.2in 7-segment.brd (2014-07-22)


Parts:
A0, A1, A2: SOLDERJUMPERREFLOW_NOPASTE; SOLDERJUMPER_REFLOW_NOPASTE
C1, C2, C3: 10uF; C0805K
D1: 1N4148; SOD-323F
JP1: HEADER-1X576MIL; 1X05_ROUND_76
LED1: BL-Q120X-41; SEGMENT_BL-Q120A
R1, R2: 10K; R0805
R3, R4, R5: 47K; R0805
U2: HT16K33_SOP28; SOP28_300MIL
U$1, U$2: FIDUCIAL; FIDUCIAL_1MM

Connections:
A0: A0.2, LED1.7, LED1.11, U2.P$23 (ROW2/A0)
A1: A1.2, LED1.6, LED1.12, U2.P$24 (ROW1/A1)
A2: A2.2, LED1.13, U2.P$25 (ROW0/A2)
GND: C1.2, C2.2, C3.2, JP1.3, U2.P$1 (VSS)
unnamed: D1.C, R3.1, R4.1, R5.1
unnamed: D1.A, LED1.1, U2.P$2 (COM0/AD)
unnamed: LED1.3, U2.P$3 (COM1/KS0)
unnamed: LED1.4, U2.P$5 (COM3/KS2)
unnamed: LED1.5, U2.P$6 (COM4)
unnamed: LED1.2, U2.P$4 (COM2/KS1)
unnamed: A2.1, R5.2
unnamed: JP1.5, R1.1, R2.1
unnamed: LED1.8, LED1.10, U2.P$22 (ROW3/K1)
unnamed: LED1.9, LED1.16, U2.P$21 (ROW4/K2)
unnamed: LED1.15, U2.P$20 (ROW5/K3)
unnamed: LED1.14, U2.P$19 (ROW6/K4)
unnamed: A1.1, R3.2
unnamed: A0.1, R4.2
SCL: JP1.1, R1.2, U2.P$26 (SCL)
SDA: JP1.2, R2.2, U2.P$27 (SDA)
VDD: C1.1, C2.1, C3.1, JP1.4, U2.P$28 (VDD)


Board: 2 copper layers, 119.6 x 50.8 mm, 18 parts (1 on the bottom side), 21 nets.

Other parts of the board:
U$3: ADAFRUIT_TEXT_30MM

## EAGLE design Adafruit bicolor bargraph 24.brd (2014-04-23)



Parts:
A0, A1, A2: SOLDERJUMPERREFLOW_NOPASTE; SOLDERJUMPER_REFLOW_NOPASTE
C1: 10uF; 0805-NO
CN1: 1X4-CLEANBIG; 1X04-CLEANBIG
D1: 1N4148; SOD-323F
LED1, LED2: KWL-R1230CDUGB; SEGMENT_BICOL_BL-AR12Z3010
R1, R2: 10K; 0805-NO
R3, R4, R5: 47K; 0805-NO
U2: 28-SOIC; SOP28_300MIL
U$1, U$2: FIDUCIAL; FIDUCIAL_1MM
U$3, U$4: MOUNTINGHOLE2.5; MOUNTINGHOLE_2.5_PLATED

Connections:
A0: A0.2, LED1.4 (A5), U2.P$23 (ROW2/A0)
A1: A1.2, LED1.3 (A3), U2.P$24 (ROW1/A1)
A2: A2.2, LED1.2 (A1), U2.P$25 (ROW0/A2)
C0: D1.A, LED1.1 (C0), LED2.1 (C0), U2.P$2 (COM0/AD)
C1: LED1.6 (C1), LED2.6 (C1), U2.P$3 (COM1/KS0)
C2: LED1.7 (C2), LED2.7 (C2), U2.P$4 (COM2/KS1)
GND: C1.2, CN1.3, U2.P$1 (VSS)
unnamed: LED2.5 (A7), U2.P$18 (ROW7/K5)
unnamed: LED1.13 (A2), U2.P$17 (ROW8/K6)
unnamed: LED2.4 (A5), U2.P$19 (ROW6/K4)
unnamed: A2.1, R5.2
unnamed: D1.C, R3.1, R4.1, R5.1
unnamed: A1.1, R3.2
unnamed: A0.1, R4.2
unnamed: LED2.2 (A1), U2.P$21 (ROW4/K2)
unnamed: LED1.5 (A7), U2.P$22 (ROW3/K1)
unnamed: LED2.3 (A3), U2.P$20 (ROW5/K3)
unnamed: LED1.12 (A4), U2.P$16 (ROW9/K7)
R10: LED1.11 (A6), U2.P$15 (ROW10/K8)
R11: LED1.10 (A8), U2.P$14 (ROW11/K9)
R12: LED2.13 (A2), U2.P$13 (ROW12/K10)
R13: LED2.12 (A4), U2.P$12 (ROW13/K11)
R14: LED2.11 (A6), U2.P$11 (ROW14/K12)
R15: LED2.10 (A8), U2.P$10 (ROW15/K13/INT)
SCL: CN1.1, R1.2, U2.P$26 (SCL)
SDA: CN1.2, R2.2, U2.P$27 (SDA)
VDD: C1.1, CN1.4, R1.1, R2.1, U2.P$28 (VDD)



Board: 2 copper layers, 100.3 x 12.7 mm, 20 parts (4 on the bottom side), 27 nets.

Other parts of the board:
U$5: ADAFRUIT_TEXT_20MM
U$6: ADAFRUIT_3.5MM

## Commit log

2014-04-23 bicolor bargraphs!
    [Adafruit bicolor bargraph 24.brd, Adafruit bicolor bargraph 24.sch]
2014-05-26 1.2" version
    [Adafruit 1.2inch 8x8 backpack.brd, Adafruit 1.2inch 8x8 backpack.sch]
2014-07-22 BIG ones
    [Adafruit 1.2in 7-segment.brd, Adafruit 1.2in 7-segment.sch]
2014-11-16 added quad alphanum
    [Adafruit 0.54 Alphanumeric v0.1.brd, Adafruit 0.54 Alphanumeric v0.1.sch]
2015-05-26 add breakout
    [Adafruit HT16K33 breakout.brd, Adafruit HT16K33 breakout.sch]
2022-02-04 Added 0.56 QT files
    [Adafruit 0.56 7-Segment QT.brd, Adafruit 0.56 7-Segment QT.sch]
2022-08-23 Add board files for 0.54 14-segment QT version.
    [Adafruit 0.54 Alphanumeric STEMMA QT.brd, Adafruit 0.54 Alphanumeric STEMMA QT.sch]
2023-02-13 adding bicolor STEMMA files
    [Adafruit Bicolor 8x8 HT16K33 STEMMA.brd, Adafruit Bicolor 8x8 HT16K33 STEMMA.sch]
2023-11-06 Update 1.2-inch 8x8 backpack files
    [Adafruit 1.2inch 8x8 backpack.brd, Adafruit 1.2inch 8x8 backpack.sch]

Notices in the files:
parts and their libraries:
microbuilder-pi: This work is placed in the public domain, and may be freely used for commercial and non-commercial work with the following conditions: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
